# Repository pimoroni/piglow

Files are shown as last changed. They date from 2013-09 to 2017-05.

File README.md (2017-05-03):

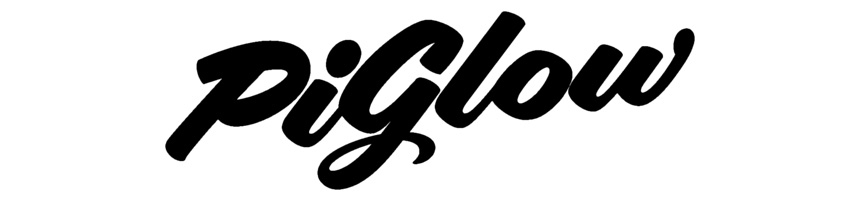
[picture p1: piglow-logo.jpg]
Piglow


The PiGlow is a small add on board for the Raspberry Pi that provides 18 individually controllable LEDs.

Learn more: https://shop.pimoroni.com/products/piglow

This repository contains the library and examples for the PiGlow board.

## Installation

**Full install ( recommended ):**

We've created a super-easy installation script that will install all pre-requisites and get your Piglow up and running in a jiffy. To run it fire up Terminal which you'll find in Menu -> Accessories -> Terminal on your Raspberry Pi desktop like so:

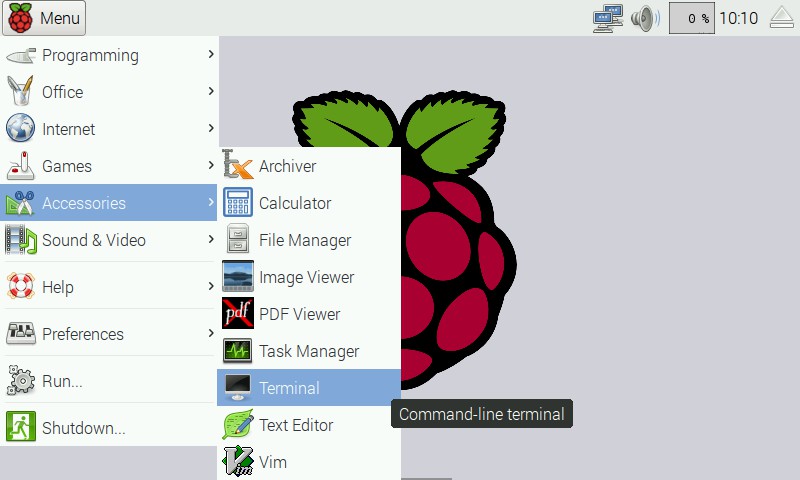
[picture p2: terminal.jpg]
Finding the terminal


In the new terminal window, run our easy installer by typing:

```bash
curl -sS https://get.pimoroni.com/piglow | bash
```

If you choose to download examples you'll find them in `/home/pi/Pimoroni/piglow/`.

**Library install for Python 3:**

on Raspbian:

```bash
sudo apt-get install python3-piglow
```
other environments: 

```bash
sudo pip3 install piglow
```

**Library install for Python 2:**

on Raspbian:

```bash
sudo apt-get install python-piglow
```
other environments: 

```bash
sudo pip2 install piglow
```

In all cases you will have to enable the i2c bus.

## Documentation & Support

* PiGlow GPIO Pinout - https://pinout.xyz/pinout/piglow
* Function reference - http://docs.pimoroni.com/piglow/
* Get help - http://forums.pimoroni.com/c/support

## Backwards Compatibility

The PiGlow Python library is designed to support examples written for Jason's PiGlow library found here: https://github.com/Boeeerb/PiGlow

It's compatible with the examples, and we've ported some over to show you how it's done.

## Using PiGlow

To use the piglow library, you'll probably want to start by importing it:

```python
import piglow
```

Now, you can turn some LEDs on:

```python
piglow.red(64)
```

Nothing will happen yet, you've got to update PiGlow with your changes. Why? Because it's quicker! If you're setting up a pattern it costs time and resources to redraw every step of that setup to the PiGlow, so we don't do that. Instead you need to call `show` like so:

```python
piglow.show()
```

A bug is a feature you can't turn off, however, so if you want to change that behaviour you can set it after importing piglow:

```python
piglow.auto_update = True
```

This will turn on auto update, refreshing the PiGlow after each change so you don't have to.

## Function Reference

### Settings
* `piglow.auto_update` - Set to True or False, determines if the PiGlow should automatically update after each LED change
* `piglow.clear_on_exit` - Set to True or False, determines if the PiGlow should be cleared on exit

### Colours
* `piglow.white( value from 0 to 255 )`
* `piglow.blue( value from 0 to 255 )`
* `piglow.green( value from 0 to 255 )`
* `piglow.yellow( value from 0 to 255 )`
* `piglow.orange( value from 0 to 255 )`
* `piglow.red( value from 0 to 255 )`

### Arm, Spoke, Leg, they're all the same thing!

`piglow.arm( index from 0 to 2, value from 0 to 255 )`

### Multiple LEDs in various different ways

The `set` method accepts a list of LEDs, a list of values, or a single LED or value, or any permutation therein:

`piglow.set(0, 255)` - sets LED 0 to full brightness

`piglow.set([1,3,5,7,9,11,13,15,17],255)` - sets all odd LEDs to full brightness

`piglow.set(0,[50,50,50])` - let the 3 LEDs starting at index 0 to 50 brightness

## Other support for PiGlow

**Gordon Henderson** (@drogon on Twitter) has very kindly added support for PiGlow into his very popular wiringPi library and even includes a basic command line tool that you can use to control your PiGlow! http://wiringpi.com/dev-lib/piglow/

**Simon Walters** (@cymplecy) has added awesome PiGlow support to his Raspberry Pi GPIO Scratch library: http://cymplecy.wordpress.com/2013/08/12/scratch-gpio-piglow-support/

**Jason Barnett** has put together a great Python class and a load of samples: https://github.com/Boeeerb/PiGlow

**Ben Lebherz** has forked Jasons project and tidied up the code a bit while adding gamma correction: https://github.com/benleb/PyGlow

**Manuel Ernst** has created a Node.js library: https://github.com/zaphod1984/node-piglow

## More information

For more information the datasheet for the SN3218 IC is included in this repository which outlines the complete communication protocol for the chip.

For those wanting to wire up their PiGlow in other ways these are the GPIO pins used by the module:

- P1 & P17 (3V3)
- P2 (5V)
- P14 (GND)
- P3 (SDA)
- P5 (SCL)

## Special Thanks

A special thanks for Jason Barnett for carrying the PiGlow torch with his original library.

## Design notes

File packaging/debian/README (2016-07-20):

README

Piglow provides 18 individually controllable LEDs. LED brightness can be controlled precisely using the SN3218 PWM driver over i2c.

Learn more: https://shop.pimoroni.com/products/piglow
For examples run: `curl -sS get.pimoroni.com/piglow | bash`

IMPORTANT

Piglow requires i2c.
To enable run `curl get.pimoroni.com/i2c | bash`
or use raspi-config and reboot your Raspberry Pi.

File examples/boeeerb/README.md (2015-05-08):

# Jason's PiGlow Examples

These examples have been ported from https://github.com/Boeeerb/PiGlow/tree/master/Examples

They all use `piglow.auto_update = True` to turn on auto updating of the PiGlow every time an LED is changed, this lets the examples work with minimal modification.

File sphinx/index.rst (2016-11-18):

.. role:: python(code)
   :language: python

.. toctree::
   :titlesonly:
   :maxdepth: 0

Welcome
-------

This documentation will guide you through the methods available in the Piglow python library.

Piglow is a simple blinky LED add-on with 18 LEDs in 6 different colours.

* More information - https://shop.pimoroni.com/products/piglow
* GPIO Pinout - https://pinout.xyz/pinout/piglow
* Get the code - https://github.com/pimoroni/piglow
* Get help - http://forums.pimoroni.com/c/support

At A Glance
-----------

.. automoduleoutline:: piglow
   :members:

Set All LEDs
------------

.. automodule:: piglow
   :noindex:
   :members: all

Clear All LEDs
--------------

.. automodule:: piglow
   :noindex:
   :members: clear

Set One Colour
--------------

Each of Piglow's rings consists of a different LED colour, from inside-to-out:

White, Blue, Green, Yellow, Orange, Red.

You can also call the colour names as functions, eg: :python:`piglow.white(255)`

.. automodule:: piglow
   :noindex:
   :members: colour

Set A Single LED
----------------

.. automodule:: piglow
   :noindex:
   :members: led

LED Bargraph
------------

.. automodule:: piglow
   :noindex:
   :members: leg_bar

LED Bargraph
------------

.. automodule:: piglow
   :noindex:
   :members: leg_bar

Turn Off
--------

.. automodule:: piglow
   :noindex:
   :members: off

Set Ring
--------

.. automodule:: piglow
   :noindex:
   :members: ring

Set LEDs
--------

.. automodule:: piglow
   :noindex:
   :members: set

Show
----

.. automodule:: piglow
   :noindex:
   :members: show

Single by Leg/Ring
------------------

.. automodule:: piglow
   :noindex:
   :members: single

Tween
-----

.. automodule:: piglow
   :noindex:
   :members: tween

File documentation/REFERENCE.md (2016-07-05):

#Piglow Function Reference

To use the piglow library, you'll probably want to start by importing it:

```python
import piglow
```

Now, you can turn some LEDs on:

```python
piglow.red(64)
```

Nothing will happen yet, you've got to update PiGlow with your changes. Why? Because it's quicker! If you're setting up a pattern it costs time and resources to redraw every step of that setup to the PiGlow, so we don't do that. Instead you need to call `show` like so:

```python
piglow.show()
```

A bug is a feature you can't turn off, however, so if you want to change that behaviour you can set it after importing piglow:

```python
piglow.auto_update = True
```

This will turn on auto update, refreshing the PiGlow after each change so you don't have to.

### Settings
* `auto_update` - Set to True or False, determines if the PiGlow should automatically update after each LED change
* `clear_on_exit` - Set to True or False, determines if the PiGlow should be cleared on exit

### Colours
* `white( value from 0 to 255 )`
* `blue( value from 0 to 255 )`
* `green( value from 0 to 255 )`
* `yellow( value from 0 to 255 )`
* `orange( value from 0 to 255 )`
* `red( value from 0 to 255 )`

### Arm, Spoke, Leg, they're all the same thing!

`arm( index from 0 to 2, value from 0 to 255 )`

### Multiple LEDs in various different ways

The `set` method accepts a list of LEDs, a list of values, or a single LED or value, or any permutation therein:

`set(0, 255)` - sets LED 0 to full brightness

`set([1,3,5,7,9,11,13,15,17],255)` - sets all odd LEDs to full brightness

`set(0,[50,50,50])` - let the 3 LEDs starting at index 0 to 50 brightness

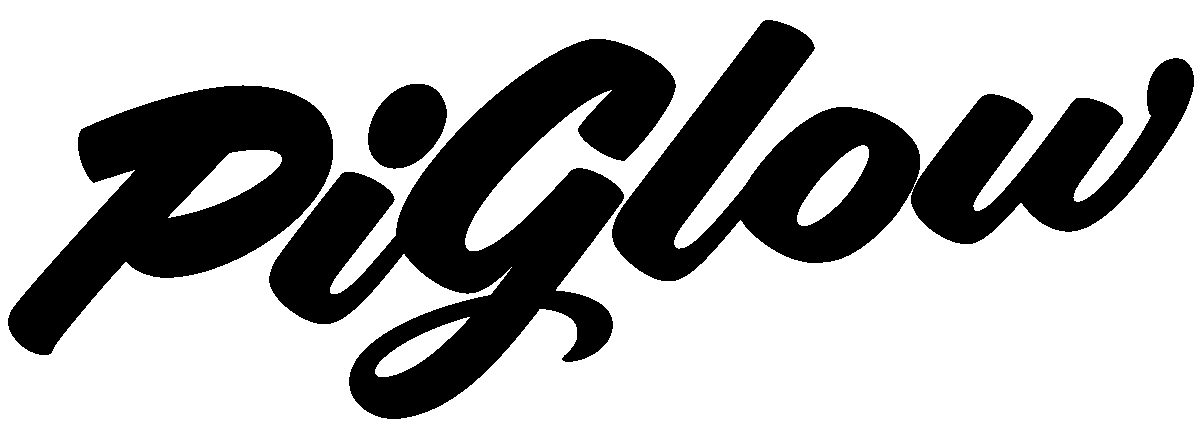
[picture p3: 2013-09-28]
hardware/piglow1200.bmp

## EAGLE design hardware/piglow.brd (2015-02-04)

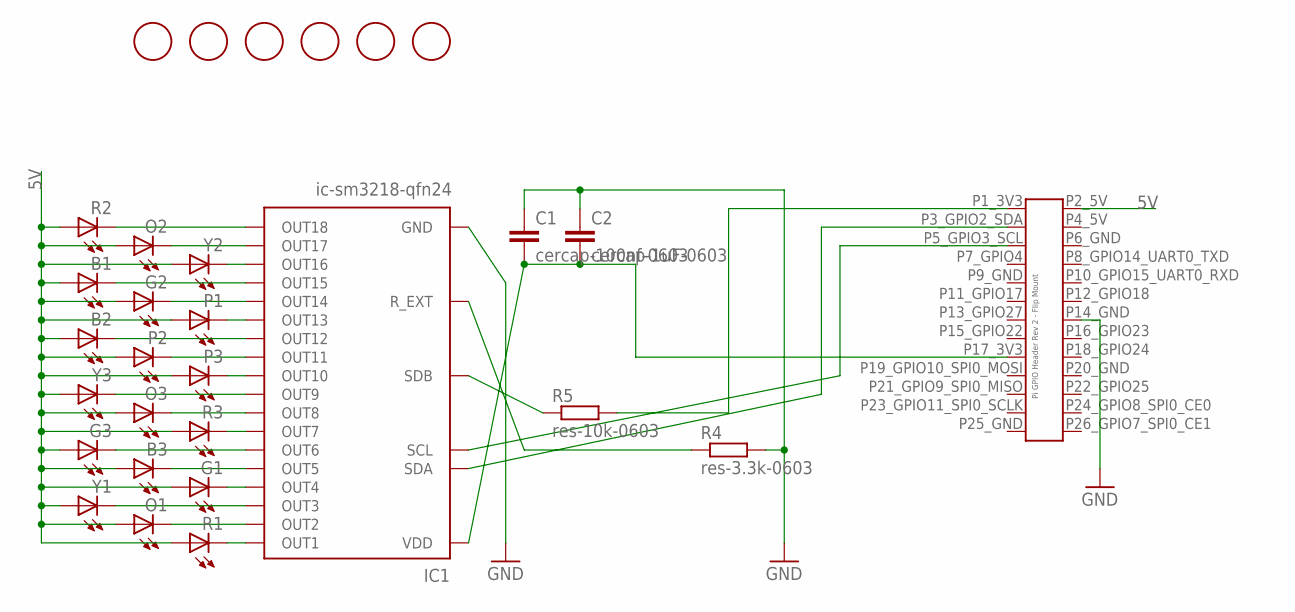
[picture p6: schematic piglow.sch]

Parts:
B1, B2, B3: led-blue-0805; CHIPLED_0805
C1: cercap-100nf-0603; C0603K
C2: cercap-1uF-0603; C0603K
G1, G2, G3: led-green-0805; CHIPLED_0805
IC1: ic-sm3218-qfn24; QFN24
O1, O2, O3: led-orange-0805; CHIPLED_0805
P1, P2, P3: led-pink-0805; CHIPLED_0805
R1, R2, R3: led-red-0805; CHIPLED_0805
R4: res-3.3k-0603; R0603
R5: res-10k-0603; R0603@1
U$1, U$2, U$3, U$5, U$6, U$7: FIDUCIAL; FIDUCIAL_1MM
U$4: FCI_89898_313LF_26P_CONNECTOR_SMT_FLIPPED
Y1, Y2, Y3: led-yellow-0805; CHIPLED_0805

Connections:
5V: B1.A, B2.A, B3.A, G1.A, G2.A, G3.A, O1.A, O2.A, O3.A, P1.A, P2.A, P3.A, R1.A, R2.A, R3.A, U$4.P2_5V, Y1.A, Y2.A, Y3.A
GND: C1.1, C2.1, IC1.4 (GND), IC1.GND, R4.2, U$4.P14_GND
unnamed: IC1.6 (SCL), U$4.P5_GPIO3_SCL
unnamed: IC1.5 (SDA), U$4.P3_GPIO2_SDA
unnamed: IC1.24 (SDB), R5.1
unnamed: IC1.1 (OUT18), R2.C
unnamed: IC1.23 (OUT17), O2.C
unnamed: IC1.22 (OUT16), Y2.C
unnamed: B1.C, IC1.21 (OUT15)
unnamed: IC1.7 (OUT1), R1.C
unnamed: IC1.8 (OUT2), O1.C
unnamed: IC1.9 (OUT3), Y1.C
unnamed: G1.C, IC1.10 (OUT4)
unnamed: B3.C, IC1.11 (OUT5)
unnamed: G3.C, IC1.12 (OUT6)
unnamed: IC1.13 (OUT7), R3.C
unnamed: IC1.14 (OUT8), O3.C
unnamed: IC1.15 (OUT9), Y3.C
unnamed: IC1.16 (OUT10), P3.C
unnamed: IC1.17 (OUT11), P2.C
unnamed: IC1.2 (R_EXT), R4.1
unnamed: IC1.19 (OUT13), P1.C
unnamed: B2.C, IC1.18 (OUT12)
unnamed: G2.C, IC1.20 (OUT14)
unnamed: C1.2, C2.2, IC1.3 (VDD), U$4.P17_3V3
P4_5V: U$4.P4_5V
VCC: R5.2, U$4.P1_3V3

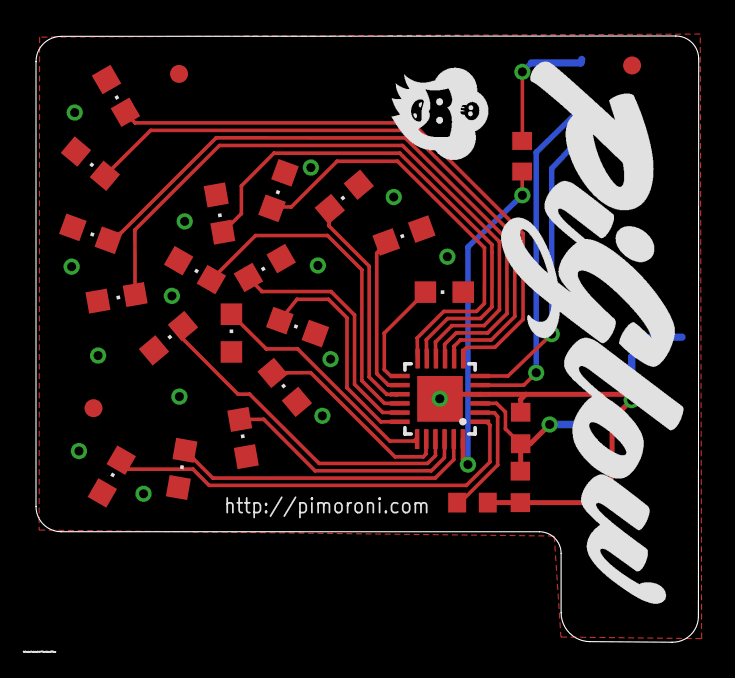
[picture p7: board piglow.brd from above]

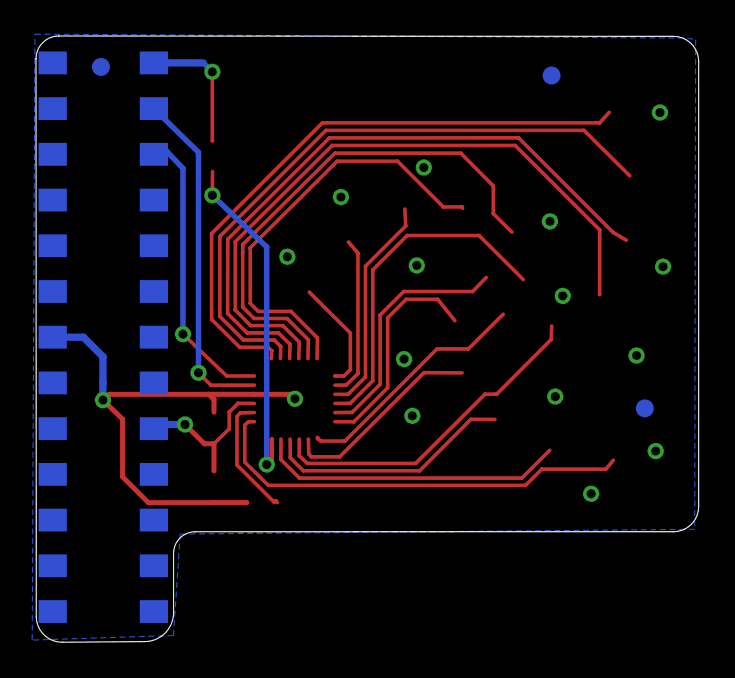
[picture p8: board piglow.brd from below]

Board: 2 copper layers, 36.8 x 33.7 mm, 30 parts (4 on the bottom side), 26 nets.

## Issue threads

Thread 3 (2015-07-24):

pip won't install piglow

clickwir, 2015-07-24:
pi@raspberrypi ~/piglow $ sudo pip install piglow
Downloading/unpacking piglow
  Could not find a version that satisfies the requirement piglow (from versions: 1.1dev, 1.2dev)
Cleaning up...
No distributions matching the version for piglow
Storing debug log for failure in /root/.pip/pip.log

pi@raspberrypi ~/piglow $ sudo cat /root/.pip/pip.log
/usr/bin/pip run on Fri Jul 24 01:44:44 2015
Downloading/unpacking piglow
  Getting page https://pypi.python.org/simple/piglow/
  URLs to search for versions for piglow:
   https://pypi.python.org/simple/piglow/
  Analyzing links from page https://pypi.python.org/simple/piglow/
    Found link https://pypi.python.org/packages/source/p/piglow/piglow-1.1dev.tar.gz#md5=cb9e06c76fd623f9f2d48809773cf458 (from https://pypi.python.org/simple/piglow/), version: 1.1dev
    Found link https://pypi.python.org/packages/source/p/piglow/piglow-1.2dev.tar.gz#md5=42ea0e3ae95a2af341d72c38857b1baa (from https://pypi.python.org/simple/piglow/), version: 1.2dev
  Ignoring link https://pypi.python.org/packages/source/p/piglow/piglow-1.1dev.tar.gz#md5=cb9e06c76fd623f9f2d48809773cf458 (from https://pypi.python.org/simple/piglow/), version 1.1dev is a pre-release (use --pre to allow).
  Ignoring link https://pypi.python.org/packages/source/p/piglow/piglow-1.2dev.tar.gz#md5=42ea0e3ae95a2af341d72c38857b1baa (from https://pypi.python.org/simple/piglow/), version 1.2dev is a pre-release (use --pre to allow).
  Could not find a version that satisfies the requirement piglow (from versions: 1.1dev, 1.2dev)
Cleaning up...
No distributions matching the version for piglow
Exception information:
Traceback (most recent call last):
  File "/usr/lib/python2.7/dist-packages/pip/basecommand.py", line 122, in main
    status = self.run(options, args)
  File "/usr/lib/python2.7/dist-packages/pip/commands/install.py", line 290, in run
    requirement_set.prepare_files(finder, force_root_egg_info=self.bundle, bundle=self.bundle)
  File "/usr/lib/python2.7/dist-packages/pip/req.py", line 1178, in prepare_files
    url = finder.find_requirement(req_to_install, upgrade=self.upgrade)
  File "/usr/lib/python2.7/dist-packages/pip/index.py", line 322, in find_requirement
    raise DistributionNotFound('No distributions matching the version for %s' % req)
DistributionNotFound: No distributions matching the version for piglow

pi@raspberrypi ~/piglow $ pip --version
pip 1.5.6 from /usr/lib/python2.7/dist-packages (python 2.7)

I don't know if this might be related: https://stackoverflow.com/a/18319230

Gadgetoid, 2016-07-06:
This was an issue with installing pre-release packages via pip, it should have been fixed in: a3378222b039b9b332a5bb806875adb881dc965f

Closed 2016-07-06.

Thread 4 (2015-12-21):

legs.py  not working in python3

RogueM, 2015-12-21:
pi@raspberrypi:~/Pimoroni/piglow$ python3 legs.py
Traceback (most recent call last):
  File "legs.py", line 13, in <module>
    piglow.set(0, map(lambda x: x - 1 if x > 1 else 0, piglow.get()))
  File "/usr/local/lib/python3.4/dist-packages/piglow.py", line 81, in set
    _set(leds, value)
  File "/usr/local/lib/python3.4/dist-packages/piglow.py", line 110, in _set
    _values[leds] = (value % 256)
TypeError: unsupported operand type(s) for %: 'map' and 'int'

Gadgetoid, 2016-07-06:
Should be fixed in: 06e86c974536c354ccaa2a127f16240eff434db1

Closed 2016-07-06.

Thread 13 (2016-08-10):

Using set method

wdecoster, 2016-08-10:
Great starting material. Although relatively simple, the piglow is making me very enthusiast and it's a nice first experience with addons on the Pi.

The readme suggests the following command: set(0, 255) - sets LED 0 to full brightness
Perhaps this is implied since the sentence above states 'The set method ...' but I guess many people will first find out that set(0, 255) is not what they expect (makes sense) and instead piglow.set(0, 255) should be used. I would suggest to clarify this.

Gadgetoid, 2017-02-08:
Good point. I've updated the readme to reflect this!

Closed 2017-02-08.

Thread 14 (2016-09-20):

Raspberry Pi 3 Support

lekkas, 2016-09-20:
Does piglow support Rpi3?

Thank you.

RogueM, 2016-09-20:
Sure, there should be no issues. Just make sure Raspbian is fully up-to-date.

lekkas, 2016-09-20:
Thanks!

Closed 2016-09-20.

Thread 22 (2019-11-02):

tween() without start parameter non-linear fade

rowlap, 2019-11-02:
`start` is an optional parameter to `tween()`, with the documented default of "the current state".

The problem is the implementation literally assigns a reference to the `_values` list, without taking a copy. As such, when `_values` changes during the loop, so does `start` as they refer to the same list.

Link to [code at time of writing](https://github.com/pimoroni/piglow/blob/63b4f16b7b2cb16033994c305e5d1d336559a7f6/library/piglow.py#L233-L263).

Steps to reproduce:
```
from piglow import tween

for _ in range(3):
    tween(2.0, [255] * 18)
    tween(2.0, [0] * 18)

for _ in range(3):
    tween(2.0, start=[0]*18, end=[255]*18)
    tween(2.0, start=[255]*18, end=[0]*18)
```

What happened:
In the first loop, LEDs fade in/out much faster than the second loop.

What's expected:
Both loops give the same result.

Gadgetoid, 2019-11-04:
I wish every issue was this detailed and descriptive. Thank you for reporting and subsequently fixing this.

Gadgetoid, 2019-11-04:
Published in release v1.2.5 - https://github.com/pimoroni/piglow/releases/tag/v1.2.5

Closed 2019-11-04.

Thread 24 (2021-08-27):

Not Compatible After Updating to Debian Bullseye repositories

ebiscaia, 2021-08-27:
Hi,

I'm having the following messages if I try to install Piglow
` curl https://get.pimoroni.com/piglow | bash                                                                                                                             ~
  % Total    % Received % Xferd  Average Speed   Time    Time     Time  Current
                                 Dload  Upload   Total   Spent    Left  Speed
100 38667  100 38667    0     0  16468      0  0:00:02  0:00:02 --:--:-- 16482

This script will install everything needed to use
Piglow

Always be careful when running scripts and commands copied
from the internet. Ensure they are from a trusted source.

If you want to see what this script does before running it,
you should run: 'curl https://get.pimoroni.com/piglow'

--- Warning ---

The Piglow installer
does not work on this version of Raspbian.
Check https://github.com/pimoroni/piglow
for additional information and support
`
and

` sudo apt-get install python3-piglow                                                                                                                                   ~
Reading package lists... Done
Building dependency tree
Reading state information... Done
Some packages could not be installed. This may mean that you have
requested an impossible situation or if you are using the unstable
distribution that some required packages have not yet been created
or been moved out of Incoming.
The following information may help to resolve the situation:

The following packages have unmet dependencies:
 libc6-dev : Breaks: libgcc-8-dev (< 8.4.0-2~) but 8.3.0-6+rpi1 is to be installed
E: Error, pkgProblemResolver::Resolve generated breaks, this may be caused by held packages.
`

The problem occurs if you try to install Piglow after these chaanges:
`
edit the file /etc/apt/sources.list changing buster to bullseye;
 edit the file  /etc/apt/sources.list.d/raspi.list changing buster to bullseye;
sudo apt update; sudo apt upgrade -y
`

Thanks

ebiscaia, 2021-08-31:
Hi,

In the end I reinstalled the Raspberry Pi OS, then Piglow and last I updated the system changing the repository list.

Thanks,

Eduardo

Closed 2023-01-13.

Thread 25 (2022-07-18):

Error: No SMBus

jaknz, 2022-07-18:
Hi,
I have an up-to-date RPi3 and have plugged my PiGlow into it. I ran the install script, which didn't throw any errors, but the example scripts all fail to run. Looks like maybe an incompatibility between Python 2/3?

```
$ ./cycle.py
0
Traceback (most recent call last):
  File "/home/pi/Pimoroni/piglow/examples/cycle.py", line 14, in <module>
    piglow.show()
  File "/usr/lib/python3/dist-packages/piglow.py", line 126, in show
    setup()
  File "/usr/lib/python3/dist-packages/piglow.py", line 323, in setup
    import sn3218
  File "/usr/lib/python3/dist-packages/sn3218.py", line 108, in <module>
    i2c = SMBus(i2c_bus_id())
FileNotFoundError: [Errno 2] No such file or directory
```

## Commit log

2013-08-12 Setting up i2c instructions
2013-08-12 Updated instructions and samples
2013-08-13 Update to pitglow.py - Turning off the LEDs when exiting
    Small update to clear down all the LEDs upon exiting the script.
2013-09-28 Added PCB layout
    [piglow.brd, piglow.sch]
2015-02-03 Updated SN3218 to new landings
    Also Tidied up Schematic and rerouted board with 10mil traces and 8mil
    clearance
    [piglow.brd, piglow.sch]
2015-02-04 Revert "Updated SN3218 to new landings"
    This reverts commit 9275a731dc1cb28da2cd379615e04127a905d690.
    [piglow.brd, piglow.sch]
2015-02-04 New SN3218 landing
    [piglow.brd, piglow.sch]
2016-05-18 Autoupdate LEDs within `all` function if `auto_update` is True
2016-05-18 Add `wave driver` example, for creating sine wave effects
2016-07-05 PCB files into hardware dir
    [piglow.brd, piglow.sch]
2016-07-06 Fixed legs.py for Python3 compatibility

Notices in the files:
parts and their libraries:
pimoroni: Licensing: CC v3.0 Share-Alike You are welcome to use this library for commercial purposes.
